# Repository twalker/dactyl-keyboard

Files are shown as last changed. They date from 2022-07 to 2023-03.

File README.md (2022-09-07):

# Wylderbuilds Dactyl Manuform - Python 3 - Cadquery
So, THIS is a fork of a fork of a fork of a... You get the idea.

This one is a direct fork of [joshreve's brilliant adaptation](https://github.com/joshreve/dactyl-keyboard)  of the original Clojure-based dactyl manuform generator redone in Python 3.
Without his work, none of this would have been nearly as easy and straightforward as it has been.  Vast kudos and thanks to him.

This repo is what I've customized and use to generate the models for the prints I sell online at Wylderbuilds, my Etsy store.

## Main Differences and How to Make it Go
Eventually, joshreve and I hope to merge our changes together, but until then, here's a quick rundown on the current changes.

* Wylderbuilds Trackball cluster -- A new, low-rider Trackball cluster. ("thumb_style": "TRACKBALL_WILD")
* Wylderbuilds BTU Trackball cluster -- An even newer Trackball cluster with ball transfer unit support. ("thumb_style": TRACKBALL_BTU")
* 1.5u pinky column support -- Outside 1.5u pinky columns can be generated ("pinky_1_5U": true, "first_1_5U_row": x, "last_1_5U_row": y)
* Full bottom rows -- Default manuforms drop the bottom row keys on outside columns, this keeps them ("full_last_rows": true)
* Clusters broken out into their own classes -- Making it easier to swap among them and add more.
* Updated Kailh Hot swap holder -- If enabled, the hot swap holder is full size and stronger.
* Cadquery builds generate STLs in addition to STEP files -- The bottom plates are (still) only generated properly when the "ENGINE": "cadquery" is set and this will now generate ready-to-print STLs (some models might need a little repair)
* OTHER MISC BITS: OLED mount wall tweaks, tweaks to screw-sizes and some wall placements, manuform angle and heights tweaked, support for an "overrides" json config file.

The main script has been reworked into a single make_dactyl() function.

The setup and run instructions are still more-or-less the same, but here's some tips:

* The docker file likely won't get far, it hasn't been maintained or updated in some time.

* To run locally, the best route is to install Anaconda or Miniconda, start a conda shell and run the "conda.sh" script.  If you're on Windows and don't want to do the WSL Linux thing, you can do the following:

1. Do the Anaconda/Miniconda bit, above.
2. In a conda shell, run the following lines:

        conda create --name=dactyl-keyboard python=3.8 -y

        conda activate dactyl-keyboard

        conda install -c conda-forge -c cadquery cadquery=master -y

        pip install dataclasses-json numpy scipy solidpython

        conda update --all -y

Then, still in the shell, from the base repo directory, run:

    python src/dactyl_manuform.py

This will churn and pump out models into the "things" directory.  In run_config.json, "ENGINE": "solid" or "cadquery" will specify OpenSCAD or STEP/STL files, respectively.  Note that the cadquery option takes considerably longer.  Openscad is best for fast iteration.

I'll update more here as things develop.

# The Dactyl-ManuForm Keyboard - Python 3 - Cadquery
This is a fork of [Dactyl-Manuform](https://github.com/tshort/dactyl-keyboard) by Tom Short, which itself is a fork of [Dactyl](https://github.com/adereth/dactyl-keyboard) by Matthew Adereth, a parameterized, split-hand, concave, columnar, ergonomic keyboard.

While the code structure remains comparable to the original, Clojure and OpenSCAD have been replaced by Python and cadquery/OpenCASCADE.  The predecessors were exceptional contributions to the ergo keyboard community by the authors but used a rather esoteric programming language, Clojure, and a relatively inconsistent geometry engine, OpenSCAD.  My hope is that by converting the code the community will have an easier time modifying and evolving this design.  

## Collaborations and Donations
I decided to start accepting donations to help offset some of the prototyping costs and development time.  There are 2 ways to contribute to this project:

### Purchase a kit or keyboard from https://www.ergohaven.xyz/
I am also supported by [ergohaven](https://www.ergohaven.xyz/).  The Dactyl-Manuforms are generated from this repository.  After working with the owner on additions to support new features we decided to collaborate to evolve the designs they can offer and to support my work.  

### Donate directly
I opened Liberapay and Ko-fi accounts to accept donations.  It is obviously not necessary, but is appreciated.  If you do donate and have something specific you really want to see, please let me know. I want to be very open that I can't promise to complete all requests as there are many reasons like engine capabilities and generator construction that can make certain features unfeasible, but I will do my best to improve this repo for you and the ergo keyboard community.

Donate using Liberapay (https://liberapay.com/joshreve/donate)



## Helpful Feedback
At this point there has been tons of feedback form the community and I greatly appreciate it.  While I can only work on this in my free time, I do my best to respond to anyone who posts a comment or question.  Feedback on issues or just possible new features is always welcome.

## Updated Geometry Engine, generating STEP files
As part of the effort to create a new engine I converted the code to cadquery/OpenCASCADE.  While OpenSCAD has provided an open source 3D engine that is extremely popular, it frankly creates barely passable STLs when you have complex geometry.  After being extremely frustrated trying to fix the mesh I realized it is just not a stable engine to create high quality files.  OpenCASCADE is extremely powerful but requires extensive detail to operate.  cadquery provided an excellent platform to run a stable geometry engine with a simplified API. 

STEP File in FreeCAD

## Added Features

### Docker Autobuild
Docker Support!

At the excellent suggestion of [martint17r](https://github.com/joshreve/dactyl-keyboard/issues?q=is%3Apr+author%3Amartint17r) 
I have added docker configurations with a Windows batch file to assist with getting setup. 
If you have 
[docker desktop](https://www.docker.com/products/docker-desktop) installed, the batch file will create the 
dactyl-keyboard image and 4 containers:

- DM-run: runs `dactyl_manuform.py`, 
- DM-config: runs `generate_configuration.py`
- DM-shell: starts an interactive session to manually run from shell
  - tip: run bash after entering to get a better shell environment
- DM-release-build: runs `model_builder.py` to generate a number of keyboard variants

All apps bindmount the `src` and `things` directory to allow editing in the host and running in the
container.  While not exactly hard drive space efficient, this hopefully helps those having issues getting
cadquery running and prevents local Python conflicts.  It works well on my computer, but I don't use
docker often, so please let me know if you find any issues with the approach.

### Refactored

Your settings are now created by `generate_configuration.py` or by direct modification of the `run_config.json` file.  
This allows you to save `run_config.json` to share your configuration.

Additionally, the OpenSCAD/solid python and OpenCASCADE/cadquery versions are merged with separate helper functions 
to decouple the generator from the target library.  This also lets me stay sane by only modifying one file for most updates.
Running `dactyl_manuform.py` will automatically load the `run_config.json` file. 

### Everyone gets a thumb cluster!

Added support of for the thumb clusters in the [carbonfet Dactyl library](https://github.com/carbonfet/dactyl-manuform).
These are the "mini" and "carbonfet" thumb clusters. Additional trackball cluster added as well more info to be added after additional build and debug time.

Feel free to try them out with by setting `'thumb_style'` to 
`'DEFAULT'`, `'MINI'`, `'CARBONFET'`, `'MINIDOX'`, `'TRACKBALL_ORBYL'`, and `'TRACKBALL_CJ'`.

Trackball features accommodate a [Perixx PERIPRO-303](https://smile.amazon.com/gp/product/B08DD6GQRV/).  Others may fit, but this was the target ball diameter for the design.  It is a little smaller than a Ploopy to try to fit better in the cluster.

Rendered and actual images to be added in future commits.

### Clippable switch mounting

Tired of hot glue and constraining the socket with "nubs"?  I've added an adjustable undercut for using the clips on 
the sockets.  May require some tweaking and little filing, but I have my DM built without any glue and you can too.  
Just use `plate_style = 'UNDERCUT'`.  I've also added an improved local undercut using `plate_style = 'NOTCH'`.

### Kailh Hotswap
Added a new switch for hot swap and a way to include any additional geometry in the key plate by use of an imported file.
For hot swap just use `plate_style = 'HS_NOTCH'`, `plate_style = 'HS_HOLE'`, or `plate_style = 'HS_NUB'`.  
To import an arbitrary geometry set the `plate_file = None` and `plate_offset = 0.0`.  
The file must be .step for OpenCascade / cadquery and .stl for openSCAD / solid python.  
The zero reference should be the key center (XY), and the top of the plate (Z).  
Plate offset is a Z-axis translation for minor adjustments without modifying the geometry file.  

**DISCLAIMER:  I have not built the hot swap version and cannot speak to the geometry.  I found it running around in various places and don't know the origin.  At least one user has claimed it works.**  

If you know the origin I would like to credit the originator.  If you test it I'd love to know how well it works or if you come up with a better geometry I'm happy to add it.  

Message me on Reddit u/j_oshreve if you are really stuck.  I don't have much time to help, but can answer the occasional question.  Also feel free to put in a pull request if you come up with something crafty and want to give others access to it.

Hot Swap in OpenSCAD

### Multiple Controller Mounts

Added an external mount for a separate controller tray.  Looks to work with lolligag's controller trays / holders:

- [Promicro V1](https://dactyl.siskam.link/loligagger-external-holder-promicro-v1.stl)
- [Promicro V2](https://dactyl.siskam.link/loligagger-external-holder-promicro-v2.stl)
- [Elite-C V1 ](https://dactyl.siskam.link/loligagger-external-holder-elite-c-v1.stl)

Just use `controller_mount_type = 'EXTERNAL'`.

Controller tray opening
Tray 1
Tray 2

This is a new feature so any feedback is appreciated.  If you have issues, message me on Reddit and I will try to help correct them.

### OLED Display Mount

Added 3 OLED mounts.  Have printed them stand alone with success.  I suggest clip, but it may require some tweaks based on your printer (over vs under sized).

OLED Clip Mounting
OLED Clip Plate

`oled_mount_type = 'CLIP'` creates an opening to set the OLED with a clip on face plate to hold it down.  This is the preferred mounting, but needs the OLED to have a removable connection.  

`oled_mount_type = 'SLIDING'` creates an opening such that you can slide the screen up through the back and into place.  Needs a piece of foam or a bit of glue to lock in place.

`oled_mount_type = 'UNDERCUT'` creates an opening with an undercut to create whatever custom holder you want.  Will not work without additional part creation from the user.

This is a new feature so any feedback is appreciated.  If you have issues, message me on Reddit and I will try to help correct them.  

### Screw Post Locations

You can now have slightly better control of screw mounts.  Set to `'screws_offset':'INSIDE'`, `'screws_offset':'OUTSIDE'` or `'screws_offset': 'ORIGINAL'` to control screw locations relative to the wall. 
Inside Screws

I am planning to deprecate outside and original at some point.  I don't see the need to carry all of them and the hidden look the best.  If you disagree feel free to let me know and I may keep a second form.

## Status / Future
This is now a bit of a monster of many minds and yet continues to bear fruit.  
I plan to continue to use this code to try new geometries and features to share for the foreseeable future.

## Installation

There are three different environments in which you can run this application. Depending on which you choose, the installation process will vary.

- [Docker Environment](#docker-environment-installation)
- [Conda Environment](#conda-environment-installation)
- [Python Environment](#python-environment-installation)

### Docker Environment Installation

Running the application with Docker is the most convenient way to do so. In addition to a straightforward installation, this also allows you to generate models in the background without having to keep a shell open.

*Note:* If you are using Windows, see [Docker Autobuild](#docker-autobuild).

Before you proceed, ensure you have installed [Docker](https://www.docker.com/) and the `docker` command is available from your terminal.

There are two tools you can use to help manage the Docker containers associated with this project. 

#### Make

If you prefer, you can use `make` to manage the containers. Type `make help` to see the available commands.

#### Bash Script

The `dactyl.sh` bash script provides a CLI to manage the containers. Type `./dactyl.sh --help` to see all CLI options.

In addition to the CLI you can run `./dactyl.sh` without any arguments to use an interactive menu. 

Upon running the script, you will be prompted to build the dactyl-keyboard Docker image.

Once the image is built, you can choose which containers to run on an as-needed basis. In general, you can start, stop, rebuild, inspect, and remove the containers via the CLI/Menu. 

You can also remove all of the Docker artifacts by running the included uninstaller.

*Tip:* Run `./dactyl.sh shell --session` to jump into a bash session inside of the shell container.

### Conda Environment Installation

After the Docker installation, Anaconda is the next best option. Before you begin, ensure you have installed [Anaconda](https://docs.anaconda.com/anaconda/install/index.html) and the `conda` command is available from your terminal.

You can install all of the dependencies by hand, but you can automate the install by running the bash script `./conda.sh`. This will create a python 3.7 environment named `dactyl-keyboard` and install all of the required dependencies.

If you would like to install into a conda environment manually, check the bash script to see all of the required commands.

If you would like to remove the conda artifacts, run `./conda.sh --uninstall`.

### Python Environment Installation

You can install the application in a regular python environment, but it is not recommended. You will not be able to take advantage of the updated geometry generated by the CadQuery engine, as this is only available via the Docker/Anaconda installation.

**Setting up the Python environment - NEW**
* [Install Python 3.X](https://www.python.org/downloads/release/python-385/) or use your [favorite distro / platform (Anaconda)](https://www.anaconda.com/products/individual) 
* It is advisable, but not necessary, to setup a virtual environment to prevent package/library incompatibility 
* [Install Numpy](https://pypi.org/project/numpy/), easiest method is `pip install numpy` or `pip3 install numpy` on linux.
* [Install dataclasses_json](https://pypi.org/project/dataclasses_json/), easiest method is `pip install dataclasses-json` or `pip3 install dataclasses-json` on linux.

**cadquery install**
* [Install scipy](https://pypi.org/project/scipy/), easiest method is `pip install scipy` or `pip3 install scipy` on linux.
* [Install cadquery](https://github.com/CadQuery/cadquery), many options (see link), but easiest method is `conda install -c conda-forge -c cadquery cadquery=2`.  Props to the creators/maintainers, this has the power of Open CASCADE with nearing the simplicity of OpenSCAD.

**OpenSCAD install**
* [Install SolidPython](https://pypi.org/project/solidpython/), easiest method is `pip install solidpython` or `pip3 install solidpython` on linux.
* [Install OpenSCAD](http://www.openscad.org/)

## Generating the design

**Generating the design - UPDATED**
* ~~Run `python dactyl_manuform_cadquery.py` or `python3 dactyl_manuform_cadquery.py`~~ 
* ~~Run `python dactyl_manuform.py` or `python3 dactyl_manuform.py`~~
* Run `generate_configuration.py` or directly edit `run_config.json` to configure the design
* Run `dactyl_manuform.py` to create the geometry (ENGINE variable in run determines method)
* This will regenerate the `things/` files (or in subdirectory if defined in config)
    * `*left.*`
    * `*right.*`
    * `*plate.*`
    * `*oled_clip.*` (if applicable)
    * `*oled_clip_test.*` (if applicable)
* Use OpenSCAD to open a `.scad` file
* Use FreeCAD or other application to open a `.step` file
* Make changes to design, repeat run step
* When done, use OpenSCAD or FreeCAD to export STL files

**The majority of the the rest of the below content is as defined by previous authors, except where noted.**

## Origin
Imgur

The main change is that the thumb cluster was adapted from the [ManuForm keyboard](https://github.com/jeffgran/ManuForm) ([geekhack](https://geekhack.org/index.php?topic=46015.0)). The walls were changed to just drop to the floor. The keyboard is paramaterized to allow adjusting the following: 

* Rows: 4 - 6 
* Columns: 5 and up
* Row curvature
* Column curvature
* Row tilt (tenting)
* Column tilt
* Column offsets
* Height

## Assembly

### Printing
Pre-generated files can be opened in OpenSCAD or FreeCAD and exported to STL.  Bottom plate is available as a step file or dxf for cadquery or a .scad file to be exported from OpenSCAD.

### Wiring

Here are materials tshort used for wiring.

* Two Arduino Pro Micros
* [Heat-set inserts](https://www.mcmaster.com/#94180a331/=16yfrx1)
* [M3 wafer-head screws, 5mm](http://www.metricscrews.us/index.php?main_page=product_info&cPath=155_185&products_id=455)
* [Copper tape](https://www.amazon.com/gp/product/B009KB86BU)
* [#32 magnet wire](https://www.amazon.com/gp/product/B00LV909HI)
* [#30 wire](https://www.amazon.com/gp/product/B00GWFECWO)
* [3-mm cast acrylic](http://www.mcmaster.com/#acrylic/=144mfom)
* [Veroboard stripboard](https://www.amazon.com/gp/product/B008CPVMMU)
* [1N4148 diodes](https://www.amazon.com/gp/product/B00LQPY0Y0)
* [Female RJ-9 connectors](https://www.amazon.com/gp/product/B01HU7BVDU/)

I wired one half using the traditional approach of using the legs of a diode to form the row connections. 
(I'm not great at soldering, so this was challenging for me.)
For this side, I used magnet wire to wire columns. That worked okay. 
The magnet wire is small enough, it wants to move around, and it's hard to tell if you have a good connection.

Imgur

For another half, I used stripboard for the row connections. 
This allowed me to presolder all of the diodes. 
Then, I hot-glued this in place and finished the soldering of the other diode ends. 
I like this approach quite a lot. 
Connections for the diodes were much easier with one end fixed down. 
On this half, I also used copper tape to connect columns. 
This worked a bit better than the magnet wire for me. 
For a future version, I may try just bare tinned copper wire for columns (something like #20). 
With the stripboard, it's pretty easy keeping row and column connections separate.

Imgur

Note that a telephone handset cable has leads that are reversed, so take this into account when connecting these leads to the controller.

The 3D printed part is the main keyboard. 
You can attach a bottom plate with screws. 
The case has holes for heat-set inserts designed to hold 3- to 6-mm long M3 screws. 
Then, I used wafer-head screws to connect a bottom plate. 
If wires aren't dangling, a bottom plate may not be needed. 
You need something on the bottom to keep the keyboard from sliding around. 
Without a plate, you could use a rubber pad, or you could dip the bottom of the keyboard in PlastiDip.

For more photos of the first complete wiring of v0.4, see [Imgur](http://imgur.com/a/v9eIO).

This is how the rows/columns wire to the keys and the ProMicro
Wire Diagram

#### Alternative row-driven wiring diagram for ProMicro:

NOTE: you also make sure the firmware is set up correctly (ex: change row pins with col pins)

Left Wire Diagram

Right Wire Diagram

### Firmware

Firmware goes hand in hand with how you wire the circuit. 
I adapted the QMK firmware [here](https://github.com/tshort/qmk_firmware/tree/master/keyboards/dactyl-manuform). 
This allows each side to work separately or together. 
This site also shows connections for the Arduino Pro Micro controllers.

## License

General Code Copyright © 2015-2021 Matthew Adereth, Tom Short, and Joshua Shreve
Mini thumb cluster Copyright © 2015-2018 Matthew Adereth, Tom Short, and Leo Lou
Carbonfet thumb cluster © 2015-2018 Matthew Adereth, Tom Short, and carbonfet (github username)

The source code for generating the models (everything excluding the [things/](things/) and [resources/](resources/) directories is distributed under the [GNU AFFERO GENERAL PUBLIC LICENSE Version 3](LICENSE).  The generated models and PCB designs are distributed under the [Creative Commons Attribution-NonCommercial-ShareAlike License Version 3.0](LICENSE-models).

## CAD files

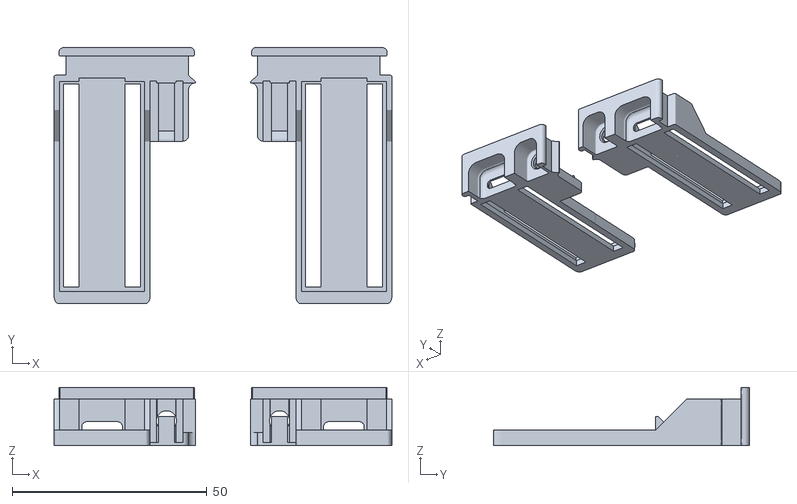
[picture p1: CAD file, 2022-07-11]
src/parts/mounts/external_blackpill_trss_x_2.stl
86.9 x 65.8 x 15.0

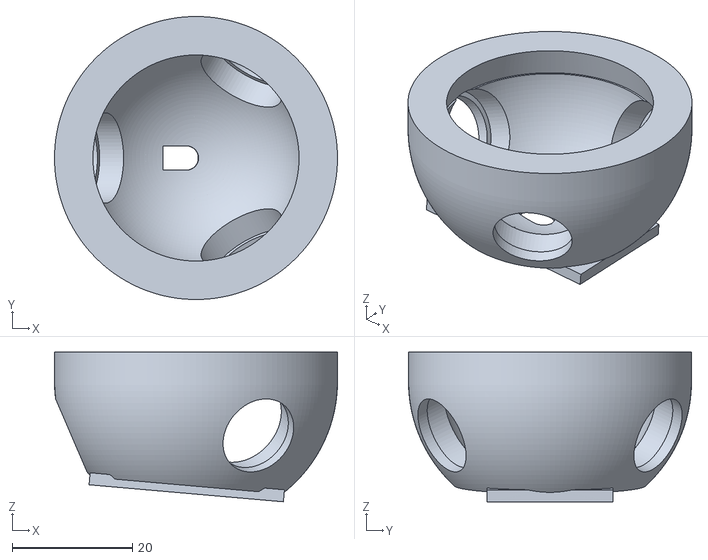
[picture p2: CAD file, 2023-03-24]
src/parts/phat_btu_socket.stl
47.0 x 47.0 x 24.8

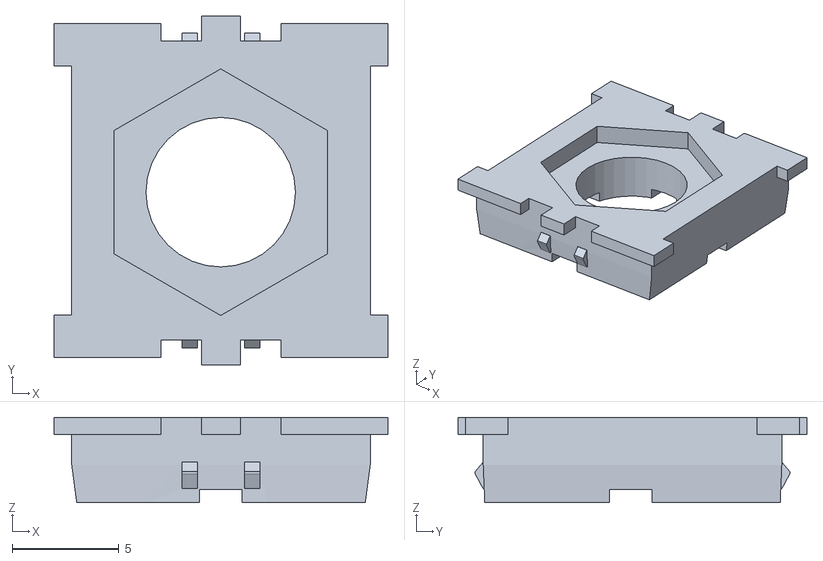
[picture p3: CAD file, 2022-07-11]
src/parts/mounts/rotary_encoder_EC11_to_MX_Adapter_V2.stl
15.6 x 16.3 x 4.00

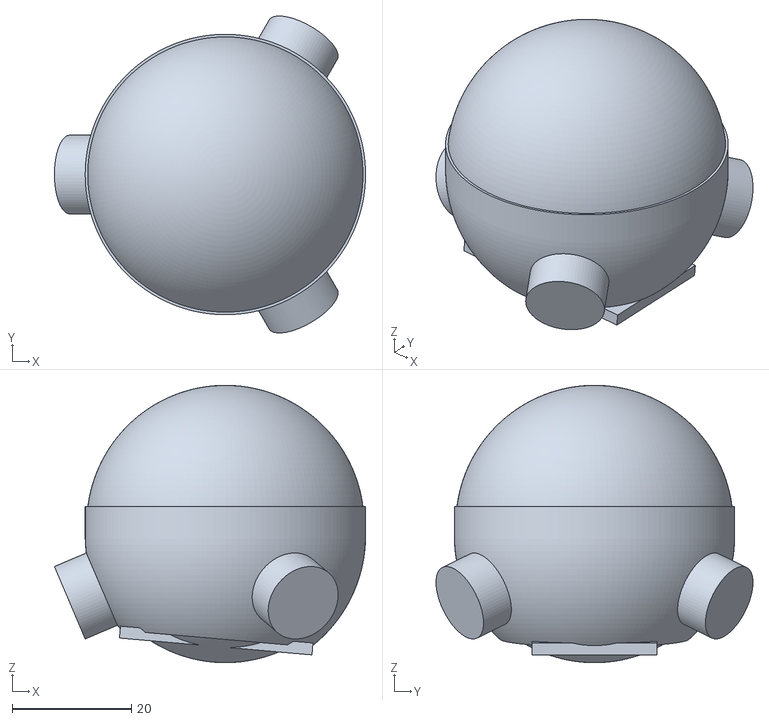
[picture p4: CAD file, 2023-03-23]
src/parts/phatter_btu_socket_cutter.stl
52.2 x 53.1 x 46.5

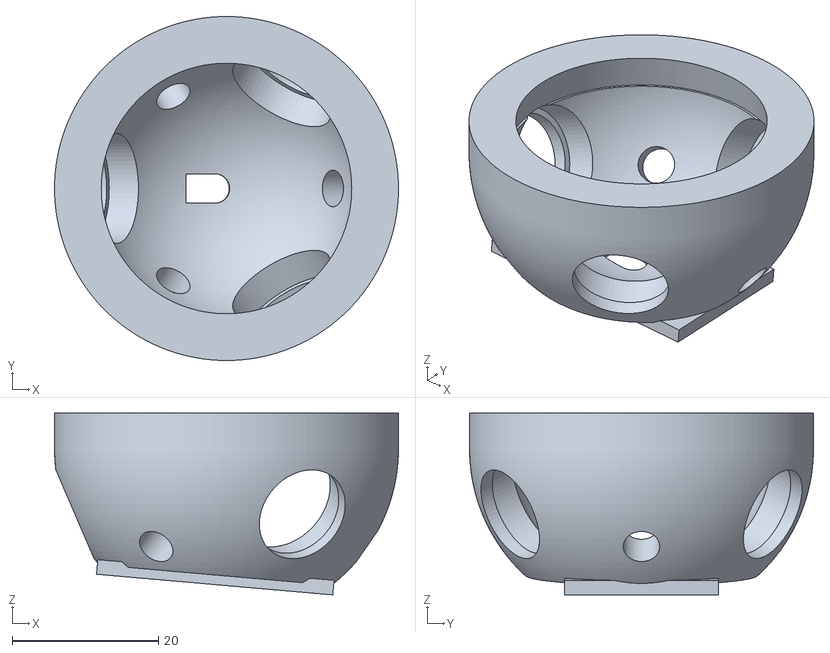
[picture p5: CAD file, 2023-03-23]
src/parts/phat_btu_socket_w_access.stl
47.0 x 47.0 x 24.8

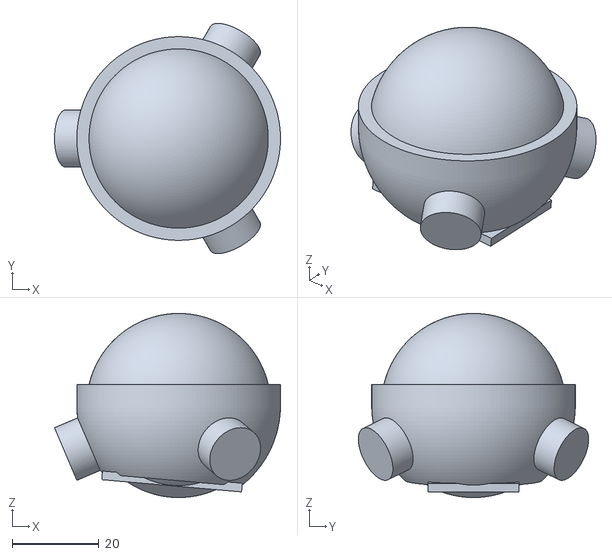
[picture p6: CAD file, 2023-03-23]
src/parts/phat_btu_socket_cutter.stl
52.2 x 53.1 x 42.5

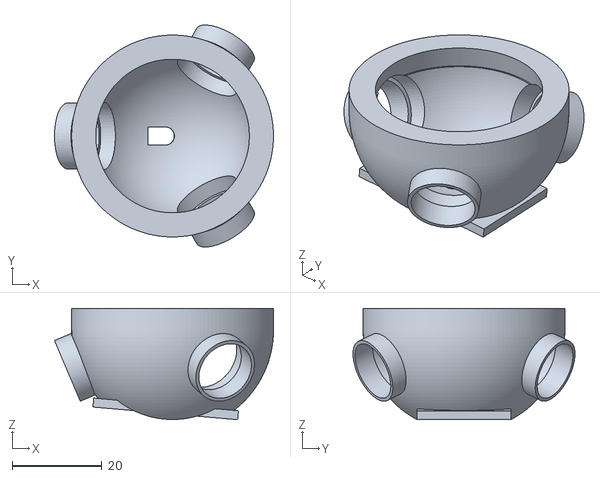
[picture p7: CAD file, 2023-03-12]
src/parts/btu_socket_2023_4_beta.stl
48.8 x 49.5 x 24.8

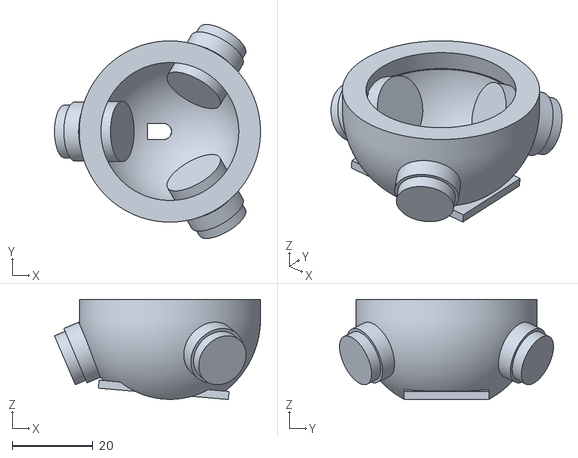
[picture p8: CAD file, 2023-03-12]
src/parts/btu_socket_cutter_2023_4_beta.stl
51.2 x 53.1 x 24.8

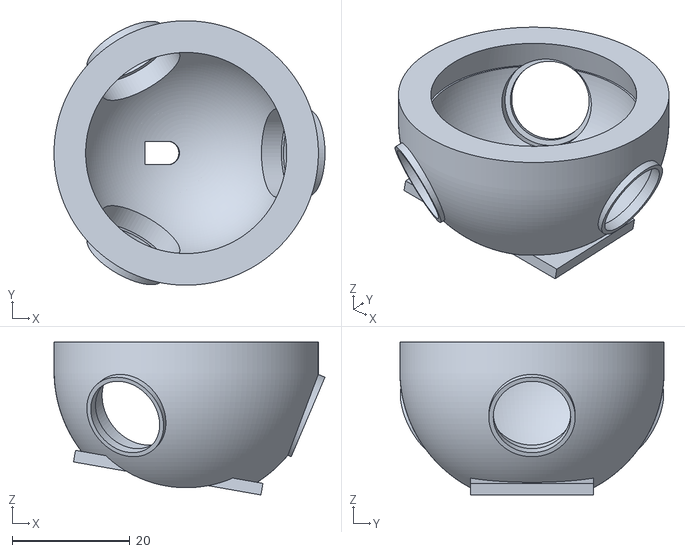
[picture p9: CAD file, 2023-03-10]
src/parts/smooth_btu_socket.stl
46.1 x 45.0 x 26.0

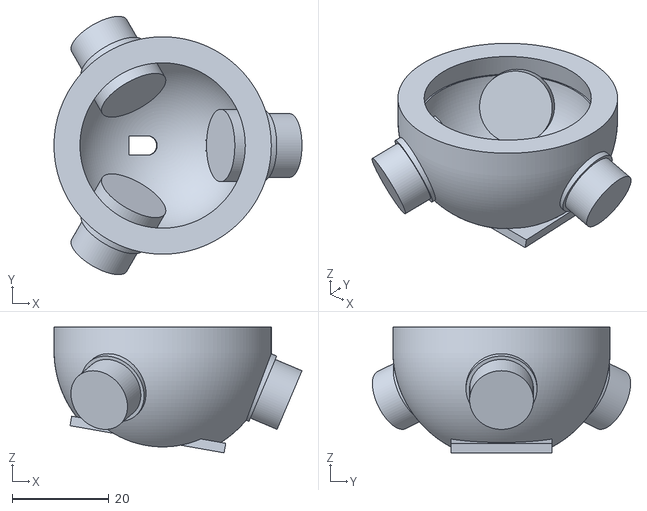
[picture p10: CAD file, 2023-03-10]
src/parts/smooth_btu_socket_cutter.stl
51.4 x 53.5 x 26.0

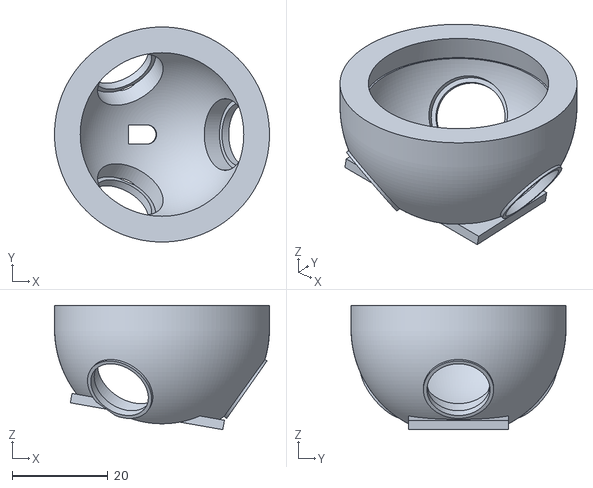
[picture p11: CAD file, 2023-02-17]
src/parts/btu_trackball_socket_feb_14_12.stl
45.0 x 45.0 x 26.0

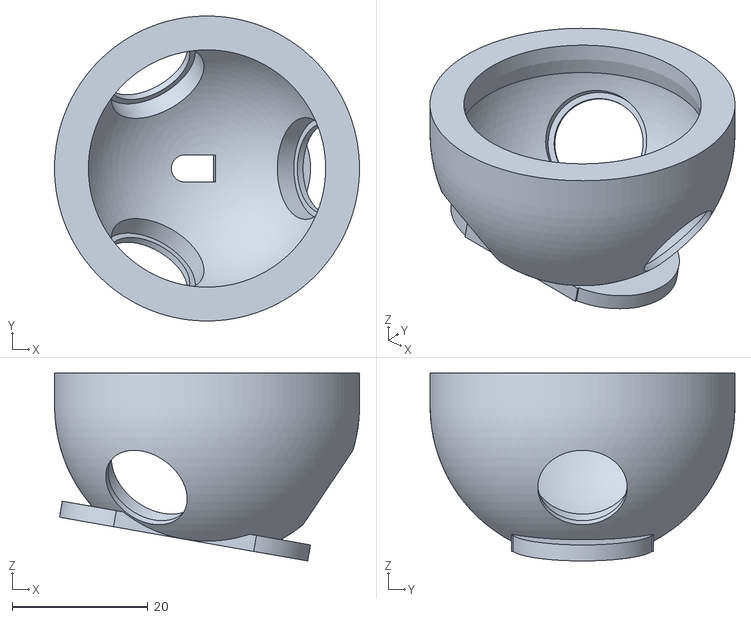
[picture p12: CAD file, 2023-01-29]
src/parts/btu_trackball_socket_wider.stl
45.0 x 45.0 x 27.7

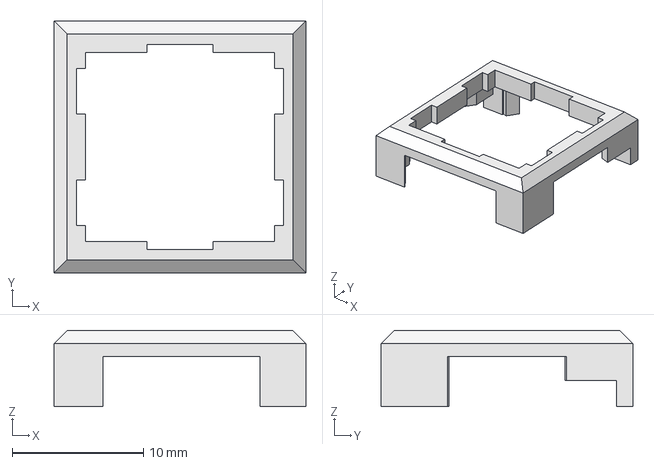
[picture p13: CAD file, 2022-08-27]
src/parts/amoeba_key_hole.step
19.2 x 19.2 x 5.80 mm

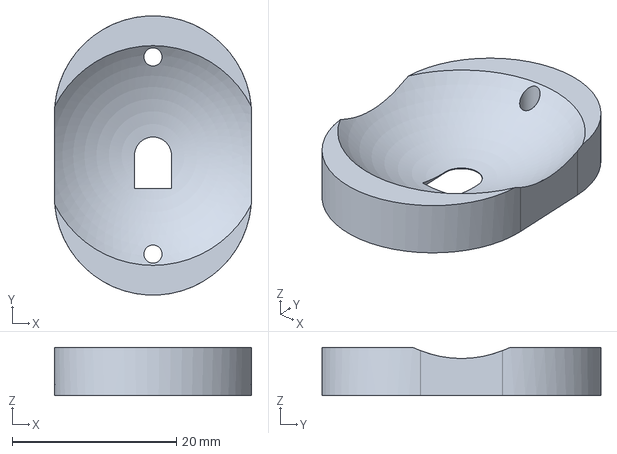
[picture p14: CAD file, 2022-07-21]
src/parts/gen_holder.step
24.0 x 34.0 x 5.90 mm

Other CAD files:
src/parts/loligaggers_x_2.stl
src/parts/hot_swap_wyld.step
src/parts/btu_trackball_socket.step
src/parts/trackball_socket_w_btus_cutter.step
src/parts/amoeba_key_hole.stl
src/parts/btu_trackball_socket.stl
src/parts/dactyl_wrist_rest_v3_left.stl
src/parts/dactyl_wrist_rest_v3_right.stl
src/parts/derek_hotswap.stl
src/parts/hot_swap_wyld.stl
src/parts/hotswap_ridged_test.step
src/parts/hotswap_ridged_test.stl
src/parts/hotswap_ridged_test_notched.stl
src/parts/trackball_socket_btu.step
src/parts/trackball_socket_w_btus_cutter.stl

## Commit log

2021-11-29 Was missing this stl
    [derek_hotswap.stl]
2021-12-20 Left cluster wasn't getting proper screw holes.
2022-01-27 Removed potential hole and blocking wall in Wilder cluster.
2022-03-02 Missing assets
    [hotswap_ridged_test.step, hotswap_ridged_test.stl, hotswap_ridged_test_notched.stl]
2022-03-15 First pass at integrated wrist rests
    [dactyl_wrist_rest_v3_left.stl, dactyl_wrist_rest_v3_right.stl]
2022-03-27 BTUs sorta in place
    [trackball_socket_btu.step, trackball_socket_btu.stl, trackball_socket_w_btus_cutter.step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]
2022-03-29 Adjusted screws again
    [trackball_socket_btu.stl]
2022-04-07 BTU updates, still needs support
    [btu_trackball_socket.step, btu_trackball_socket.stl, trackball_socket_btu.stl]
2022-04-14 Lowered mini cluster by 4mm
2022-04-22 Updated hot swap socket
    [hot_swap_wyld.step, hot_swap_wyld.stl]
2022-05-01 Screw hole in space fixed
2022-05-08 Logo and screw offsets params and always generate left half items, never simply mirror the right.
2022-06-18 Added 'resin' parameter which short-circuits trackball supports if true.
2022-06-19 Screw holes, insert holes, and external holder width adjusted.
2022-06-20 Tightened width of external holder.
2022-07-11 Added some mounts, basic Elite C "lolligagger" mounts and blackpill external mounts.
    [external_blackpill_trss_x_2.stl, external_elite_c_trrs_x_2.stl, rotary_encoder_EC11_to_MX_Adapter_V2.stl]
2022-07-21 Oops. Forgot da step file.
    [gen_holder.step]
2022-07-30 Added amoeba mounts
    [amoeba_key_hole.step, amoeba_key_hole.stl]
2022-08-08 More space on carbonfet top switch hole. Fixed an issue with latest Cadquery
2022-08-24 Added standard loligaggers
    [loligaggers_x_2.stl]
2022-08-27 Amoeba mount working well
    [amoeba_key_hole.step, amoeba_key_hole.stl]
2022-10-04 magnets attempt 1
2022-10-23 Cut OLED section out of run_config.json
2022-10-28 Rotated socket to keep bearing at the bottom
2022-11-02 Added better offsets around top trackball wild key, shifted cluster forward 1mm and top key back 1mm.
2022-11-11 Update screws and apply updates from wilder branch
2022-11-27 Stronger magnet supports
2022-12-20 Deeper magnet slots
2023-01-06 Tinkered with BTU socket and trackball three.
2023-01-29 Tweaked BTU socket
    [btu_trackball_socket_wider.stl]
2023-02-11 Fixed the damn magnet depth, dammit and damn.
2023-02-17 Updated BTU socket
    [btu_trackball_socket_feb_14_12.stl]
2023-03-04 Adjusted magnet offsets for plate and case
2023-03-10 Slight tweak to trackball cluster placement, 1mm further forward, and put all trackball-related funcs in the same damn spot in dactyl_manuform.py.
    [smooth_btu_socket.stl, smooth_btu_socket_cutter.stl]
2023-03-12 Generated better all-row models
    [btu_socket_2023_4_beta.stl, btu_socket_cutter_2023_4_beta.stl]
2023-03-17 Adding USB-C mount point
2023-03-19 Reverted magnet depths
2023-03-19 USB-C and TRRS mounts
2023-03-20 First pass at USB-C and TRRS mount points.
2023-03-23 Reverted Trackball-three to bearings trackball.
    Updated btu socket to phat_btu_socket_w_access and phat_btu_socket_cutter.
    [phat_btu_socket_cutter.stl, phat_btu_socket_w_access.stl, phatter_btu_socket_cutter.stl]
2023-03-23 Ensure 3-row versions are handled for OLED mounts properly
2023-04-01 Thicker front wall on wide left wall with carbonfet
    Fixed screw diameter and top depth
2023-04-09 Preparing to drop magnets
2023-04-11 Slight bump to brass insert radii
2023-04-12 Adjustments to inserts and sphere tops
2023-04-16 Shifted right screwholes a bit
2023-04-26 Reverted default cluster screw position
2023-05-07 Freakin' magnet bottom conditional...
2023-05-08 Inserts, inserts
2023-08-13 Added encoder in wall bits.
2023-08-20 Wider insert bores
2023-08-28 Revert to standard insert size.
